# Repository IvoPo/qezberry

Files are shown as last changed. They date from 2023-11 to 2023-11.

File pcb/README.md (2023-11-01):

# QEZBerry PCB

### Features

- Powered by an rp2040
- Basic ESD and overvoltage protection
- Centered USB type-C port for a detachable cable
- Multiple layout options (see below)
- Fully programmable using [QMK](https://qmk.fm) and [Vial](https://get.vial.today)

---

### Supported layouts

layout1
layout2
layout3

---

### Preview

pcb

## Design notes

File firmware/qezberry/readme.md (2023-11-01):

# QEZberry

QEZ with rp2040.

## Derived from QEZ

qez
gezberry
A seamless gasketmounted QAZ-like 40% keyboard

* Keyboard Maintainer: IvoPo
* Hardware Supported: QEZberry rev2.0 PCB
* Hardware Availability: TDB
* Case and Plate fully compatible with QEZ: [Open source project](https://github.com/kb-elmo/QEZ)

Make example for this keyboard (after setting up your build environment):

    make qezberry:default

Flashing example for this keyboard:

    make kb_elmo/qez:default:flash

See the [build environment setup](https://docs.qmk.fm/#/getting_started_build_tools) and the [make instructions](https://docs.qmk.fm/#/getting_started_make_guide) for more information. Brand new to QMK? Start with our [Complete Newbs Guide](https://docs.qmk.fm/#/newbs).

## Bootloader

* **Bootmagic reset**: Hold down the top left key and plug in the keyboard
* **Physical reset button**: Briefly press the button labeled "RESET" on the back of the PCB
* **Physical boot switch**: Hold down Button labeled "BOOT" and Briefly press the button labeled "RESET" on the back of the PCB

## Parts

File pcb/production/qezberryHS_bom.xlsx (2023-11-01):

Comment | Designator | Footprint | JLCPCB Part #（optional）
1u | C1,C4,C8,C10 | C_0402 | C1523
10u | C17 | C_0805 | C1710
27pF | C2,C3 | C_0402 | C1557
100n | C5,C6,C7,C9,C11,C12,C13,C14,C15,C16 | C_0402 | C307331
D_Small | D1,D2,D3,D4,D5,D6,D7,D8,D9,D10,D11,D12,D13,D14,D15,D16,D17,D18,D19 | D_SOT-23-3 | C68978
Polyfuse_Small | F1 | F_1206 | C69688
5.1k | R1,R2 | R_0805 | C27834
5.1k | R10 | R_0402 | C25905
27 | R3,R4 | R_0402 | C25092
1k | R5,R9 | R_0402 | C11702
10k | R6 | R_0805 | C17414
10k | R8,R11 | R_0402 | C25744
SW_Push | Boot,Reset | SW_SPST_CK_RS282G05A3 | C92584
XC6206P332MR | U1 | SOT-23 | C5446
W25Q128JVS | U2 | SOIC-8_5.3x5.3x1.27P | C97521
RP2040 | U3 | LQFN-56_EP_7.0x7.0x0.4P | C2040
SRV05-4 | U4 | SOT-23-6 | C85364
USB_C_Receptacle_USB2.0 | USB1 | TYPE-C-31_L8.94_W7.3 | C165948
Crystal_GND24_Small | Y1 | SMD-CRY-3225_4P | C9002
LED | D20 | LED_0603 | C72041
WS2812B | D21,D22,D23,D24,D25,D26,D27,D28,D29 | LED_WS2812B_PLCC4_5.0x5.0mm_P3.2mm | C2843785
ezmate 4pin | J3,J5 | Molex_Pico-EZmate_78171-0004 | C588524

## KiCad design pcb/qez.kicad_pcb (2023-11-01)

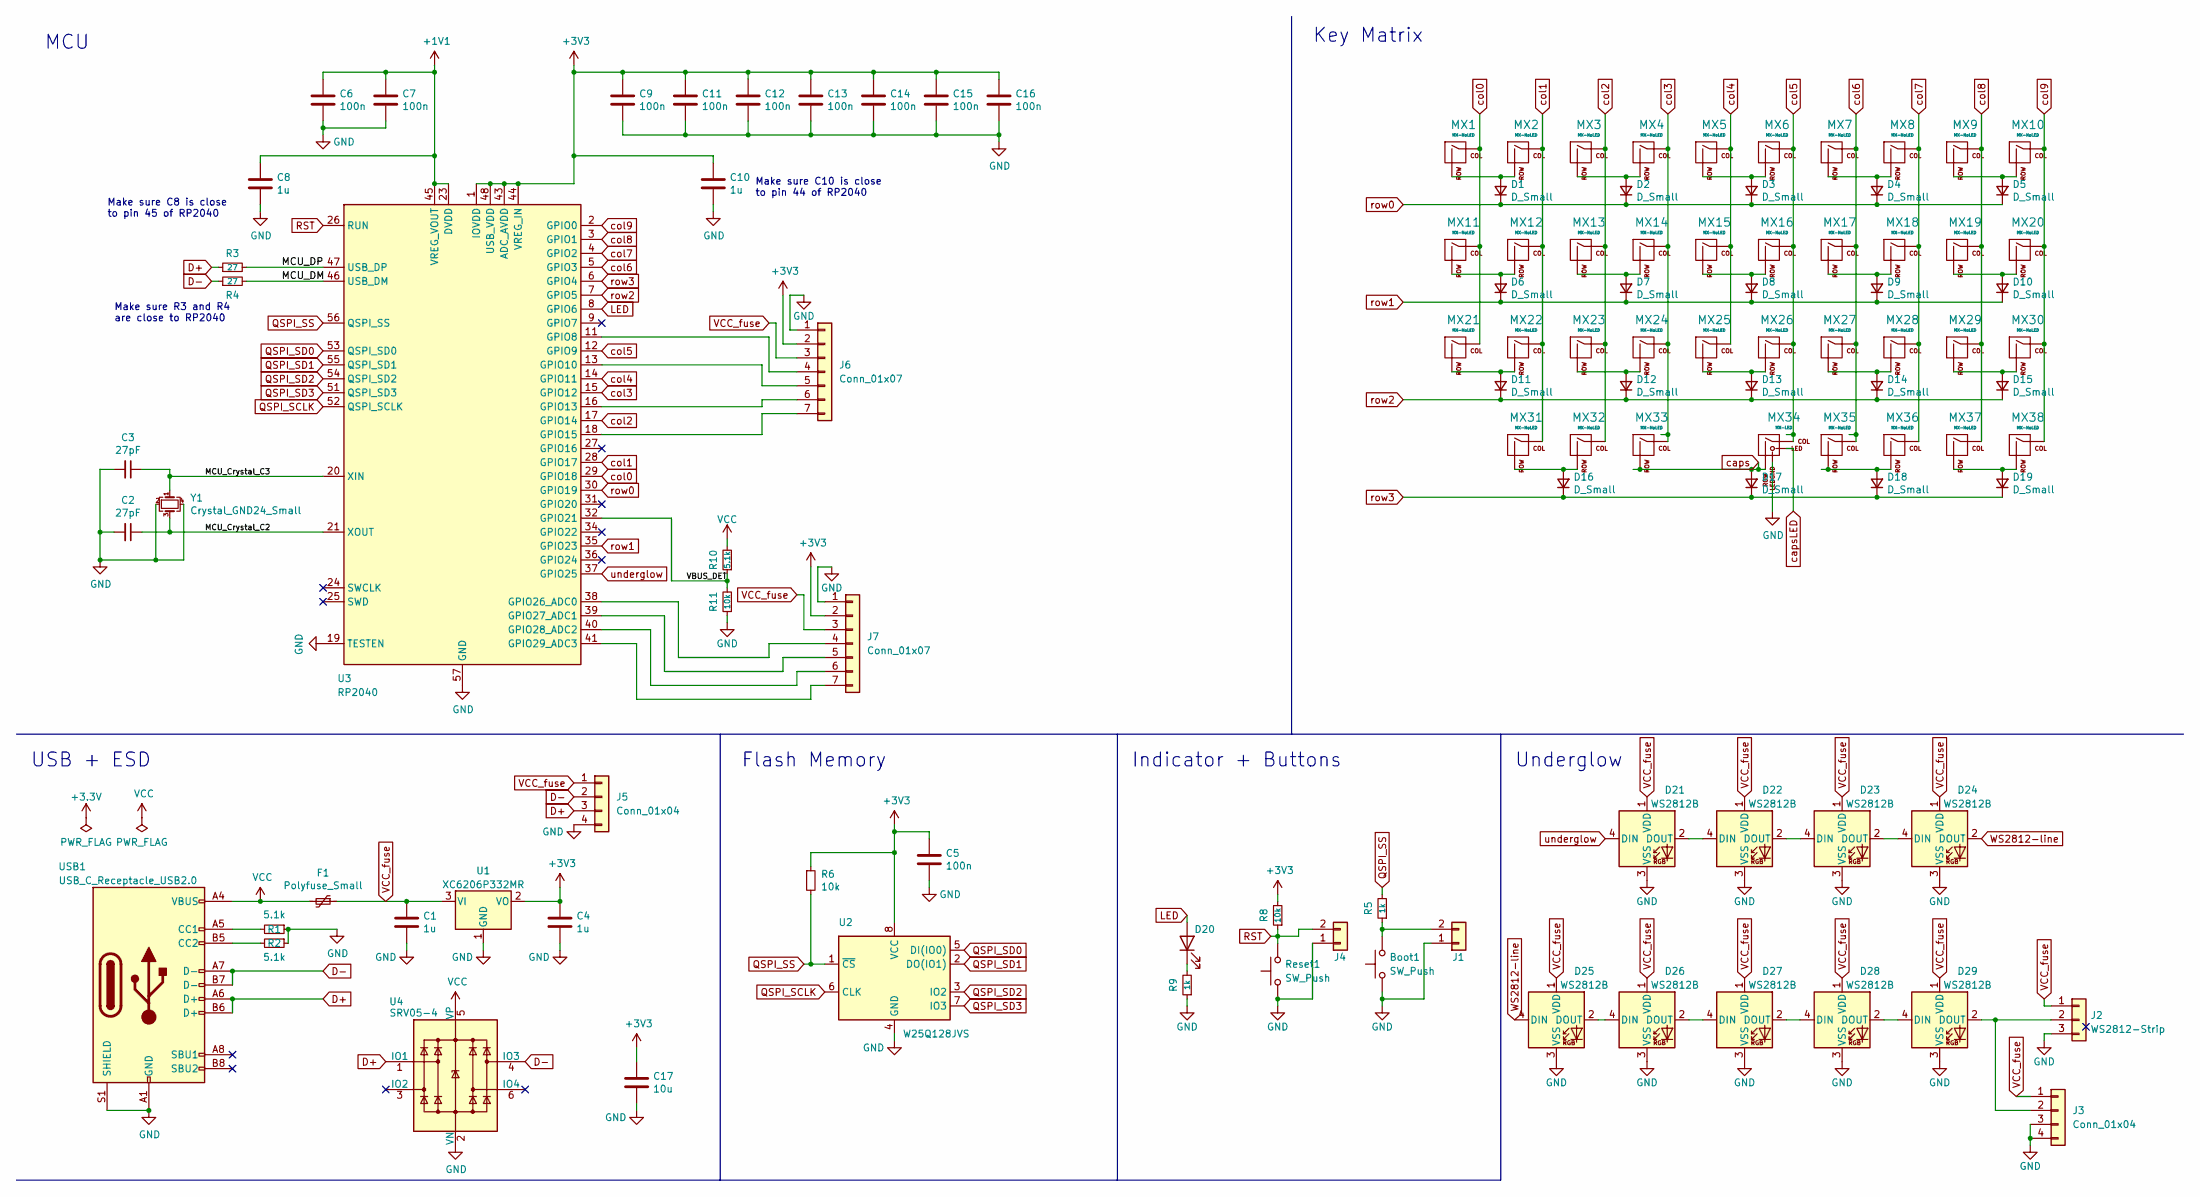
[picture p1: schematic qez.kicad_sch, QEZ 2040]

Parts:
Boot1: SW_Push; SW_SPST_SKQG_WithStem; LCSC C319433
C1, C4, C8, C10: 1u; C_0402_1005Metric; LCSC C1523
C2, C3: 27pF; C_0402_1005Metric; LCSC C1557
C5, C6, C7, C9, C11, C12, C13, C14, C15, C16: 100n; C_0402_1005Metric; LCSC C307331
C17: 10u; C_0805_2012Metric; LCSC C1710
D1, D2, D3, D4, D5, D6, D7, D8, D9, D10, D11, D12, D13, D14, D15, D16, D17, D18, D19: D_Small; D_SOT-23_ANK; LCSC C68978
D20: LED; LED_0402_1005Metric; LCSC C130719
D21, D22, D23, D24, D25, D26, D27, D28, D29: WS2812B; LED_WS2812B_PLCC4_5.0x5.0mm_P3.2mm
F1: Polyfuse_Small; Fuse_1206_3216Metric; LCSC C69688
J1, J4: Conn_01x02; PinHeader_1x02_P1.27mm_Vertical
J2: WS2812-Strip; PinHeader_1x03_P1.27mm_Vertical
J3: Conn_01x04; Molex_Pico-EZmate_78171-0004_1x04-1MP_P1.20mm_Vertical
J5: Conn_01x04
J6: Conn_01x07; PinSocket_1x07_P2.00mm_Vertical
J7: Conn_01x07; PinSocket_1x07_P1.27mm_Vertical
MX1, MX2, MX3, MX4, MX5, MX6, MX7, MX8, MX9, MX12, MX13, MX14, MX15, MX16, MX17, MX18, MX19, MX20, MX22, MX23, MX24, MX25, MX26, MX27, MX28, MX29, MX31, MX32, MX36, MX37, MX38: MX-NoLED; MXOnly-1U-NoLED
MX10, MX11: MX-NoLED; MXOnly-1.25U-NoLED
MX21: MX-NoLED; MXOnly-1.75U-NoLED
MX30: MX-NoLED; MXOnly-1.5U-NoLED
MX33: MX-NoLED; MXOnly-2.75U-ReversedStabilizers-NoLED
MX34: MX-LED; MXOnly-1.25U
MX35: MX-NoLED; MXOnly-2.25U-ReversedStabilizers-NoLED
R1, R2: 5.1k; R_0805_2012Metric; LCSC C27834
R3, R4: 27; R_0402_1005Metric; LCSC C17561
R5, R9: 1k; R_0402_1005Metric; LCSC C11702
R6: 10k; R_0805_2012Metric; LCSC C17414
R8, R11: 10k; R_0402_1005Metric; LCSC C25744
R10: 5.1k; R_0402_1005Metric; LCSC C25905
Reset1: SW_Push; SW_SPST_SKQG_WithStem; LCSC C319433
U1: XC6206P332MR; SOT-23; LCSC C5446
U2: W25Q128JVS; SOIC-8_5.23x5.23mm_P1.27mm; LCSC C97521
U3: RP2040; QFN-56-1EP_7x7mm_P0.4mm_EP3.2x3.2mm; LCSC C2040
U4: SRV05-4; SOT-23-6; LCSC C85364
USB1: USB_C_Receptacle_USB2.0; USB_C_Receptacle_HRO_TYPE-C-31-M-12; LCSC C165948
Y1: Crystal_GND24_Small; Crystal_SMD_3225-4Pin_3.2x2.5mm; LCSC C13738

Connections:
+1V1: C6.1, C7.1, C8.1, U3.23 (DVDD), U3.45 (VREG_VOUT), U3.50 (DVDD)
+3V3: C4.1, C5.1, C9.1, C10.1, C11.1, C12.1, C13.1, C14.1, C15.1, C16.1, C17.1, J6.2, J7.2, R6.1, R8.2, U1.2 (VO), U2.8 (VCC), U3.1 (IOVDD), U3.10 (IOVDD), U3.22 (IOVDD), U3.33 (IOVDD), U3.42 (IOVDD), U3.43 (ADC_AVDD), U3.44 (VREG_IN), U3.48 (USB_VDD), U3.49 (IOVDD)
/MCU_Crystal_C2: C2.1, U3.21 (XOUT), Y1.3
/MCU_Crystal_C3: C3.1, U3.20 (XIN), Y1.1
/MCU_DM: R4.2, U3.46 (USB_DM)
/MCU_DP: R3.2, U3.47 (USB_DP)
/VBUS_DET: R10.1, R11.2, U3.32 (GPIO21)
D+: J5.3, R3.1, U4.1 (IO1), USB1.A6 (D+), USB1.B6 (D+)
D-: J5.2, R4.1, U4.4 (IO3), USB1.A7 (D-), USB1.B7 (D-)
GND: Boot1.1, C1.2, C2.2, C3.2, C4.2, C5.2, C6.2, C7.2, C8.2, C9.2, C10.2, C11.2, C12.2, C13.2, C14.2, C15.2, C16.2, C17.2, D21.3 (VSS), D22.3 (VSS), D23.3 (VSS), D24.3 (VSS), D25.3 (VSS), D26.3 (VSS), D27.3 (VSS), D28.3 (VSS), D29.3 (VSS), J1.1, J2.3, J3.3, J3.4, J4.1, J5.4, J6.1, J7.1, MX34.4 (LEDGND), R1.1, R2.1, R9.1, R11.1, Reset1.1, U1.1 (GND), U2.4 (GND), U3.19 (TESTEN), U3.57 (GND), U4.2 (VN), USB1.A1 (GND), USB1.A12 (GND), USB1.B1 (GND), USB1.B12 (GND), USB1.S1 (SHIELD), Y1.2, Y1.4
LED: D20.2 (A), U3.8 (GPIO6)
unnamed: D1.2 (A), MX1.2 (ROW), MX2.2 (ROW)
unnamed: D2.2 (A), MX3.2 (ROW), MX4.2 (ROW)
unnamed: D3.2 (A), MX5.2 (ROW), MX6.2 (ROW)
unnamed: D4.2 (A), MX7.2 (ROW), MX8.2 (ROW)
unnamed: D5.2 (A), MX9.2 (ROW), MX10.2 (ROW)
unnamed: D6.2 (A), MX11.2 (ROW), MX12.2 (ROW)
unnamed: D7.2 (A), MX13.2 (ROW), MX14.2 (ROW)
unnamed: D8.2 (A), MX15.2 (ROW), MX16.2 (ROW)
unnamed: D9.2 (A), MX17.2 (ROW), MX18.2 (ROW)
unnamed: D10.2 (A), MX19.2 (ROW), MX20.2 (ROW)
unnamed: D11.2 (A), MX21.2 (ROW), MX22.2 (ROW)
unnamed: D12.2 (A), MX23.2 (ROW), MX24.2 (ROW)
unnamed: D13.2 (A), MX25.2 (ROW), MX26.2 (ROW)
unnamed: D14.2 (A), MX27.2 (ROW), MX28.2 (ROW)
unnamed: D15.2 (A), MX29.2 (ROW), MX30.2 (ROW)
unnamed: D16.2 (A), MX31.2 (ROW), MX32.2 (ROW)
unnamed 28: D18.2 (A), MX35.2 (ROW), MX36.2 (ROW); also elsewhere on the board
unnamed: D19.2 (A), MX37.2 (ROW), MX38.2 (ROW)
unnamed: D20.1 (K), R9.2
unnamed: D21.2 (DOUT), D22.4 (DIN)
unnamed: D22.2 (DOUT), D23.4 (DIN)
unnamed: D23.2 (DOUT), D24.4 (DIN)
unnamed: D25.2 (DOUT), D26.4 (DIN)
unnamed: D26.2 (DOUT), D27.4 (DIN)
unnamed: D27.2 (DOUT), D28.4 (DIN)
unnamed: D28.2 (DOUT), D29.4 (DIN)
unnamed: D29.2 (DOUT), J2.2, J3.2
unnamed: Boot1.2, J1.2, R5.1
unnamed: J6.4, U3.11 (GPIO8)
unnamed: J6.5, U3.13 (GPIO10)
unnamed: J6.6, U3.16 (GPIO13)
unnamed: J6.7, U3.18 (GPIO15)
unnamed: J7.4, U3.38 (GPIO26_ADC0)
unnamed: J7.5, U3.39 (GPIO27_ADC1)
unnamed: J7.6, U3.40 (GPIO28_ADC2)
unnamed: J7.7, U3.41 (GPIO29_ADC3)
unnamed: R1.2, USB1.A5 (CC1)
unnamed: R2.2, USB1.B5 (CC2)
QSPI_SCLK: U2.6 (CLK), U3.52 (QSPI_SCLK)
QSPI_SD0: U2.5 (DI(IO0)), U3.53 (QSPI_SD0)
QSPI_SD1: U2.2 (DO(IO1)), U3.55 (QSPI_SD1)
QSPI_SD2: U2.3 (IO2), U3.54 (QSPI_SD2)
QSPI_SD3: U2.7 (IO3), U3.51 (QSPI_SD3)
QSPI_SS: R5.2, R6.2, U2.1 (~CS), U3.56 (QSPI_SS)
RST: J4.2, R8.1, Reset1.2, U3.26 (RUN)
VCC: F1.2, R10.2, U4.5 (VP), USB1.A4 (VBUS), USB1.A9 (VBUS), USB1.B4 (VBUS), USB1.B9 (VBUS)
VCC_fuse: C1.1, D21.1 (VDD), D22.1 (VDD), D23.1 (VDD), D24.1 (VDD), D25.1 (VDD), D26.1 (VDD), D27.1 (VDD), D28.1 (VDD), D29.1 (VDD), F1.1, J2.1, J3.1, J5.1, J6.3, J7.3, U1.3 (VI)
WS2812-line: D24.2 (DOUT), D25.4 (DIN)
caps: D17.2 (A), MX33.2 (ROW), MX34.2 (ROW)
col0: MX1.1 (COL), MX11.1 (COL), MX21.1 (COL), U3.29 (GPIO18)
col1: MX2.1 (COL), MX12.1 (COL), MX22.1 (COL), MX31.1 (COL), U3.28 (GPIO17)
col2: MX3.1 (COL), MX13.1 (COL), MX23.1 (COL), MX32.1 (COL), U3.17 (GPIO14)
col3: MX4.1 (COL), MX14.1 (COL), MX24.1 (COL), MX33.1 (COL), U3.15 (GPIO12); also elsewhere on the board
col4: MX5.1 (COL), MX15.1 (COL), MX25.1 (COL), U3.14 (GPIO11)
col5: MX6.1 (COL), MX16.1 (COL), MX26.1 (COL), MX34.1 (COL), U3.12 (GPIO9); also elsewhere on the board
col6: MX7.1 (COL), MX17.1 (COL), MX27.1 (COL), MX35.1 (COL), U3.5 (GPIO3); also elsewhere on the board
col7: MX8.1 (COL), MX18.1 (COL), MX28.1 (COL), MX36.1 (COL), U3.4 (GPIO2)
col8: MX9.1 (COL), MX19.1 (COL), MX29.1 (COL), MX37.1 (COL), U3.3 (GPIO1)
col9: MX10.1 (COL), MX20.1 (COL), MX30.1 (COL), MX38.1 (COL), U3.2 (GPIO0)
row0: D1.1 (K), D2.1 (K), D3.1 (K), D4.1 (K), D5.1 (K), U3.30 (GPIO19)
row1: D6.1 (K), D7.1 (K), D8.1 (K), D9.1 (K), D10.1 (K), U3.35 (GPIO23)
row2: D11.1 (K), D12.1 (K), D13.1 (K), D14.1 (K), D15.1 (K), U3.7 (GPIO5)
row3: D16.1 (K), D17.1 (K), D18.1 (K), D19.1 (K), U3.6 (GPIO4)
underglow: D21.4 (DIN), U3.37 (GPIO25)

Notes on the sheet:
Key Matrix
USB + ESD
Make sure C10 is close to pin 44 of RP2040
Make sure R3 and R4 are close to RP2040
Make sure C8 is close to pin 45 of RP2040
Underglow
MCU
Flash Memory
Indicator + Buttons

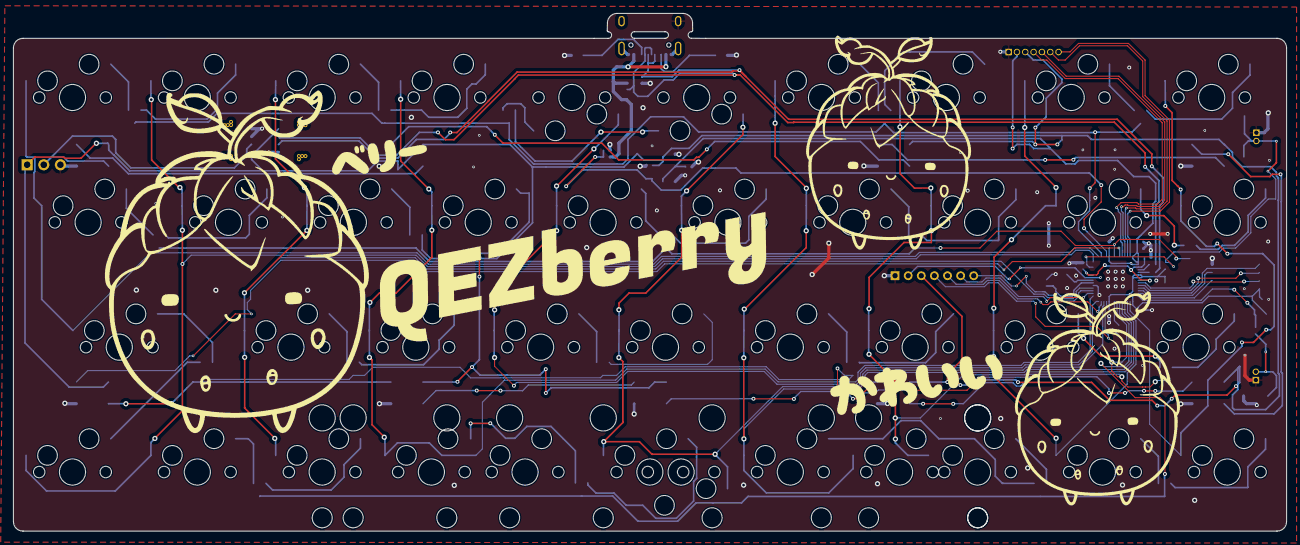
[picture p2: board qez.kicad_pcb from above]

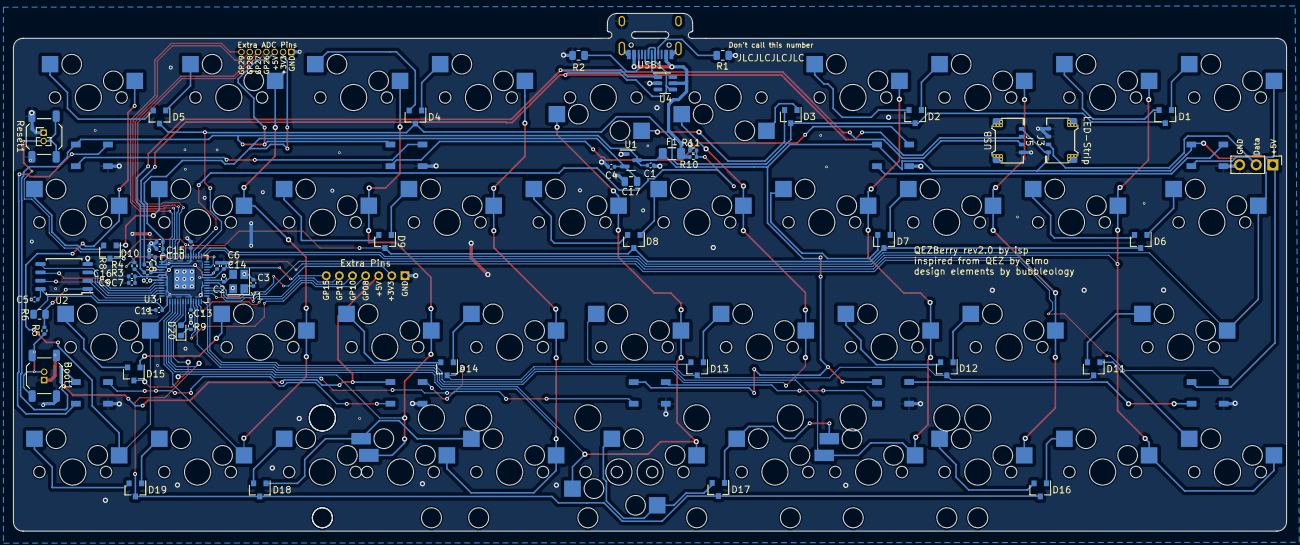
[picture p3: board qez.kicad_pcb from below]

Board: 2 copper layers, 194.3 x 79.0 mm, 113 parts (72 on the bottom side), 76 nets.

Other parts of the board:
MX39: MX-NoLED; MXOnly-2.25U-Hotswap-ReversedStabilizers
MX40: MX-NoLED; MXOnly-2U-Hotswap-ReversedStabilizers
MX41: MX-LED; MXOnly-6.25U-Hotswap-ReversedStabilizers-LED

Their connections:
unnamed: MX39.2 (ROW), MX41.2 (ROW)
unnamed 28: MX40.2 (ROW); also elsewhere on the board
col3: MX39.1 (COL); also elsewhere on the board
col5: MX41.1 (COL); also elsewhere on the board
col6: MX40.1 (COL); also elsewhere on the board

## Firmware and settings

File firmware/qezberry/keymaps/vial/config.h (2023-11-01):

/* SPDX-License-Identifier: GPL-2.0-or-later */

#pragma once

#define VIAL_KEYBOARD_UID {0xD3, 0x73, 0x34, 0x3F, 0x58, 0xD2, 0xE0, 0x0A}
#define VIAL_UNLOCK_COMBO_COLS { 1, 1}
#define VIAL_UNLOCK_COMBO_ROWS { 0, 9}

//Vial limits
#define VIAL_COMBO_ENTRIES 64
#define VIAL_TAP_DANCE_ENTRIES 64
#define VIAL_KEY_OVERRIDE_ENTRIES 64
#define DYNAMIC_KEYMAP_LAYER_COUNT 24

#define WS2812_DI_PIN GP25
#undef RGBLED_NUM
//without LED-Strip
#define RGBLED_NUM 9
//with LED-Strip
//#define RGBLED_NUM 64

//RGBLIGHT Animations
#define RGBLIGHT_EFFECT_SNAKE
#define RGBLIGHT_EFFECT_ALTERNATING
#define RGBLIGHT_EFFECT_BREATHING
#define RGBLIGHT_EFFECT_CHRISTMAS
#define RGBLIGHT_EFFECT_KNIGHT
#define RGBLIGHT_EFFECT_RAINBOW_MOOD
#define RGBLIGHT_EFFECT_RAINBOW_SWIRL
#define RGBLIGHT_EFFECT_RGB_TEST
#define RGBLIGHT_EFFECT_SNAKE
#define RGBLIGHT_EFFECT_STATIC_GRADIENT
#define RGBLIGHT_EFFECT_TWINKLE

//RGBLIGHT Animation Settings
#define RGBLIGHT_LIMIT_VAL 240
#define RGBLIGHT_EFFECT_KNIGHT_OFFSET 9
#define RGBLIGHT_EFFECT_KNIGHT_LED_NUM 55
#define RGBLIGHT_EFFECT_KNIGHT_LENGTH 10
#define RGBLIGHT_EFFECT_SNAKE_LENGTH 10

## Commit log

2023-11-01 add production and kicad project files
    [qez-B_Cu.gbr, qez-B_Mask.gbr, qez-B_Paste.gbr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]
2023-11-01 fix pcb preview pics
2023-11-11 Added Doubleclick Reset for Bootloader Added Compiled Firmware with and without LED-Strip
    [config.h]
